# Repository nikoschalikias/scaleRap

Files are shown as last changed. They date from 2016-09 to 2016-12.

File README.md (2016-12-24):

# scaleRap   

A scaleable and robust open-hardware Reprap 3D printer based on aluminium profile 40mm. Designed in Fusion 360 CAD. [project page](https://nikoschalikias.github.io/scaleRap/)  

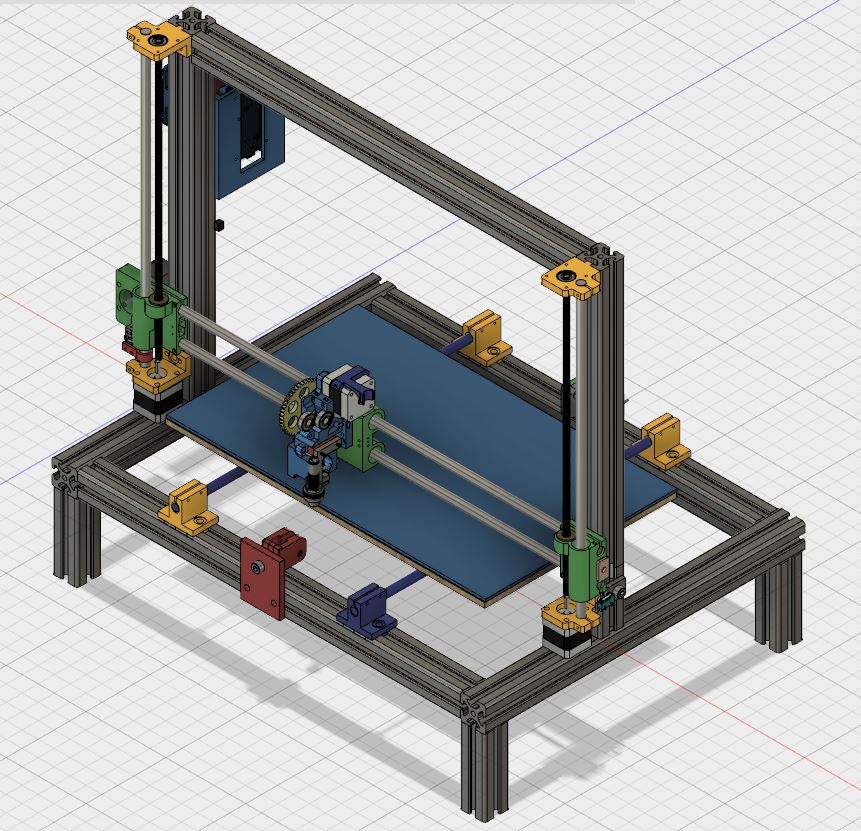
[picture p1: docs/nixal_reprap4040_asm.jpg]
nixal i3 nixal_reprap4040 3D printer
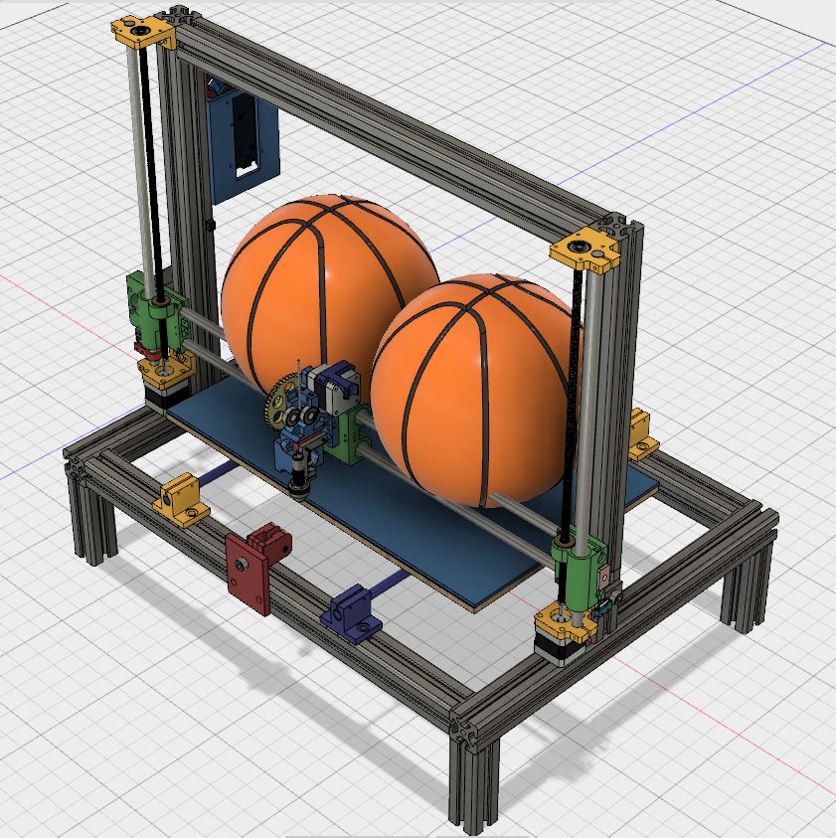
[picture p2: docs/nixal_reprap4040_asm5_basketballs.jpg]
nixal i3 nixal_reprap4040 3D printer
   
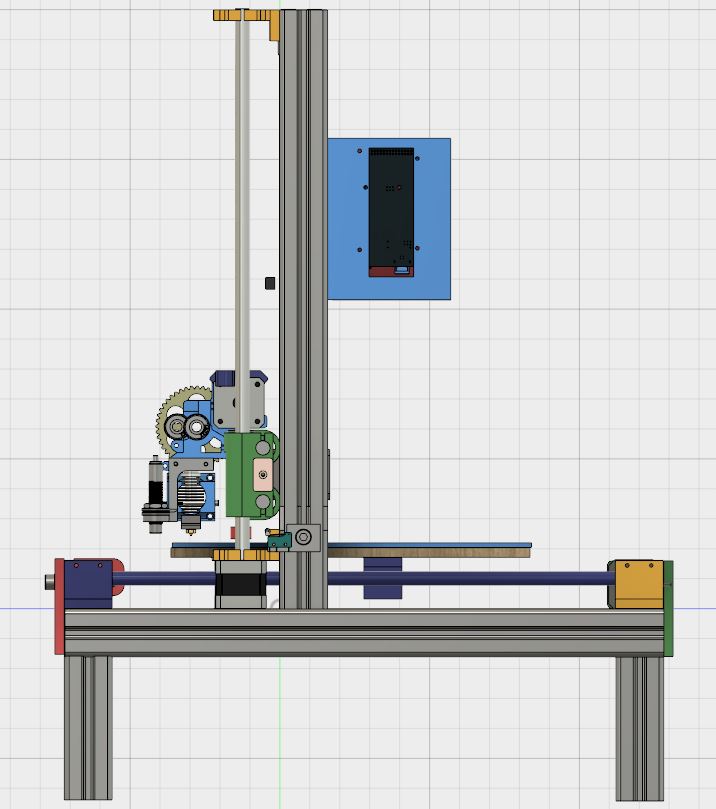
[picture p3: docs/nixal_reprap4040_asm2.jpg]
nixal i3 nixal_reprap4040 3D printer
 
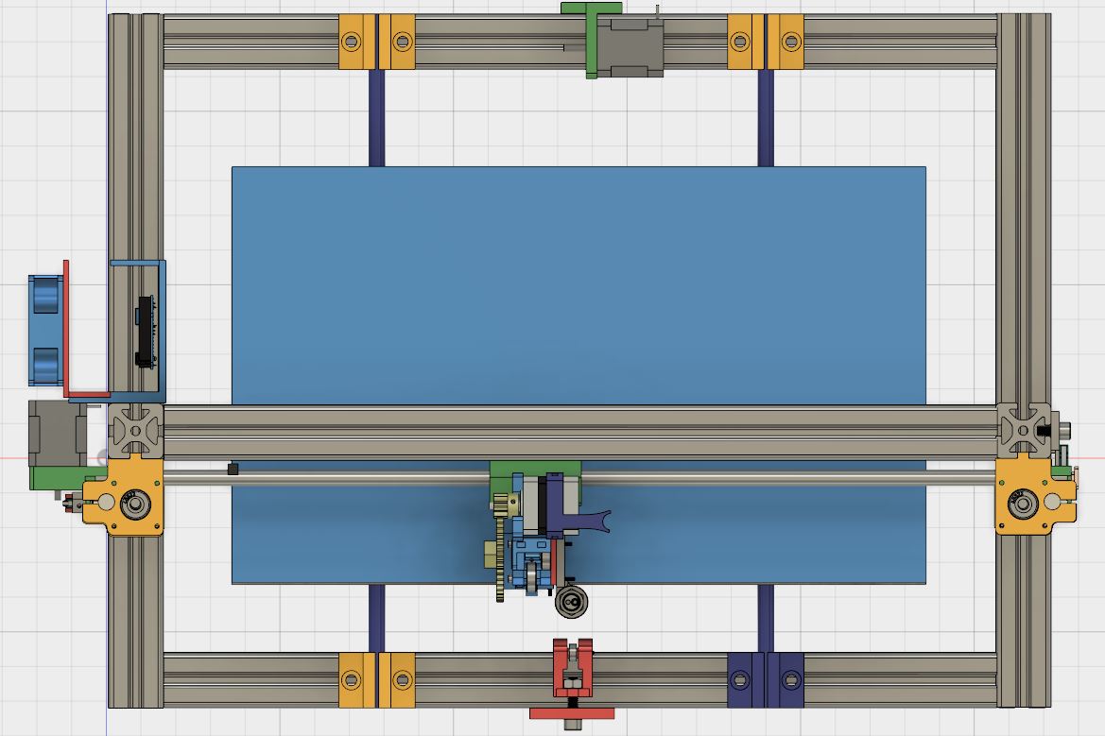
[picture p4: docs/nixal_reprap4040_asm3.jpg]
nixal i3 nixal_reprap4040 3D printer
 
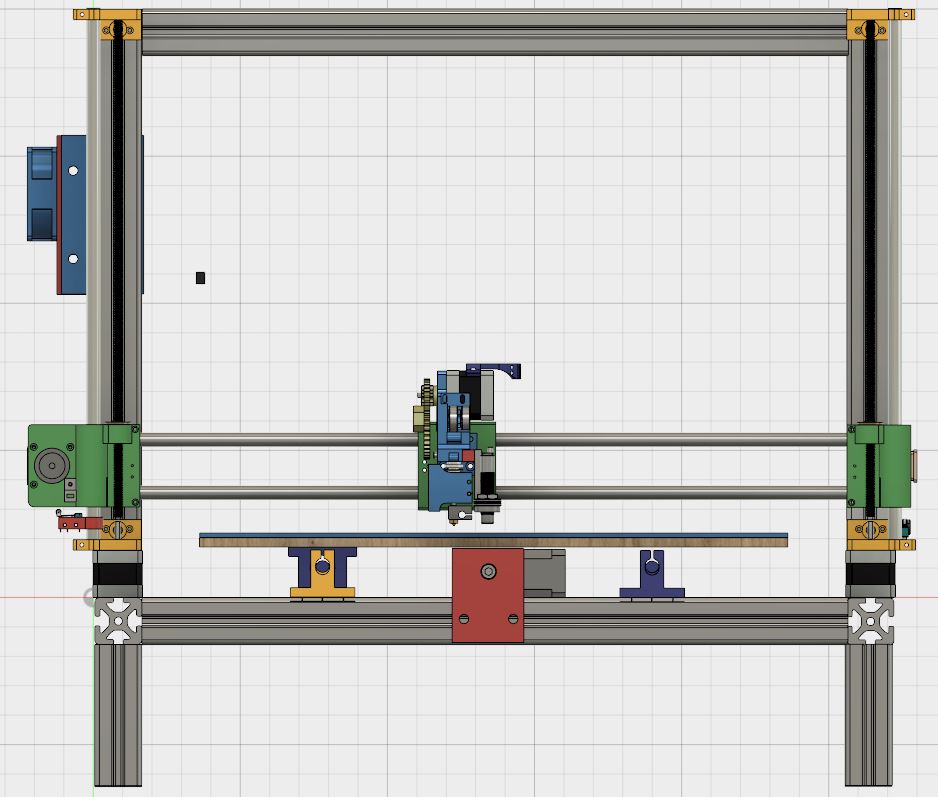
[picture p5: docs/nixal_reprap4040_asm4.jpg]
nixal i3 nixal_reprap4040 3D printer


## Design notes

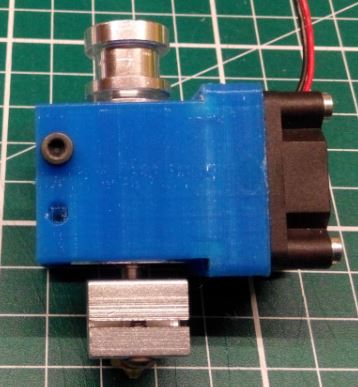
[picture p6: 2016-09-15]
docs/nixal_reprap4040_e3dsecureFan30mm_10.JPG

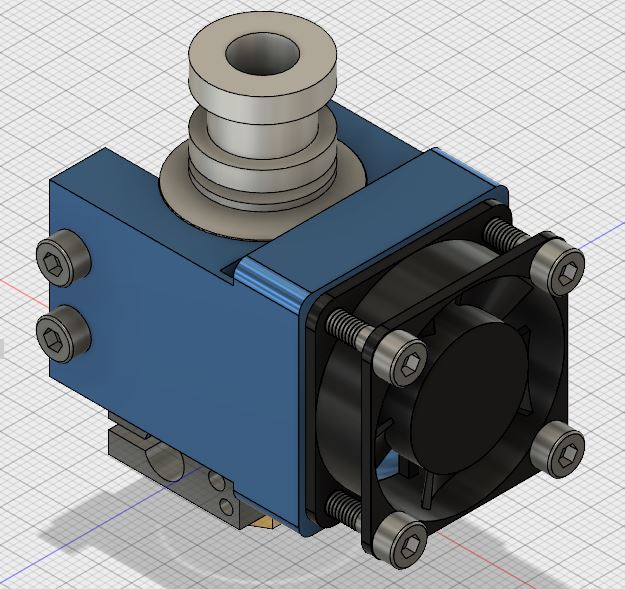
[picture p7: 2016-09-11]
docs/nixal_reprap4040_e3dsecureFan30mm_2.JPG

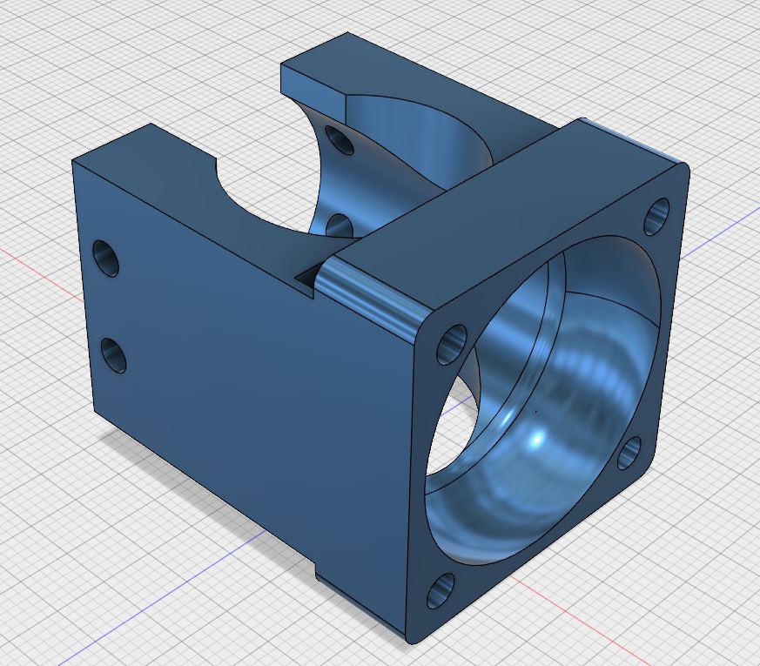
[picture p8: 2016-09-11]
docs/nixal_reprap4040_e3dsecureFan30mm_6.JPG

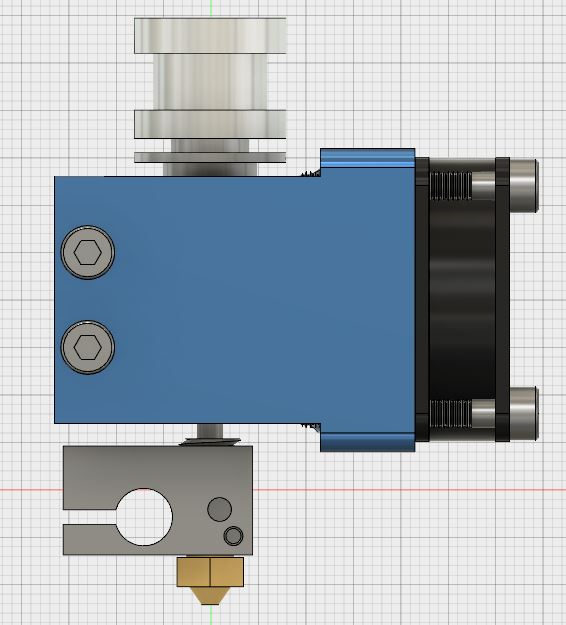
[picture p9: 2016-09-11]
docs/nixal_reprap4040_e3dsecureFan30mm_5.JPG

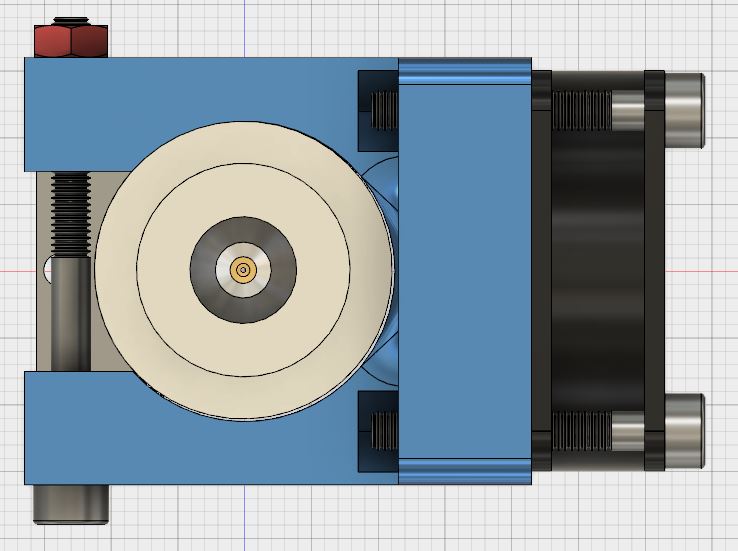
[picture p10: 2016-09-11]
docs/nixal_reprap4040_e3dsecureFan30mm_3.JPG

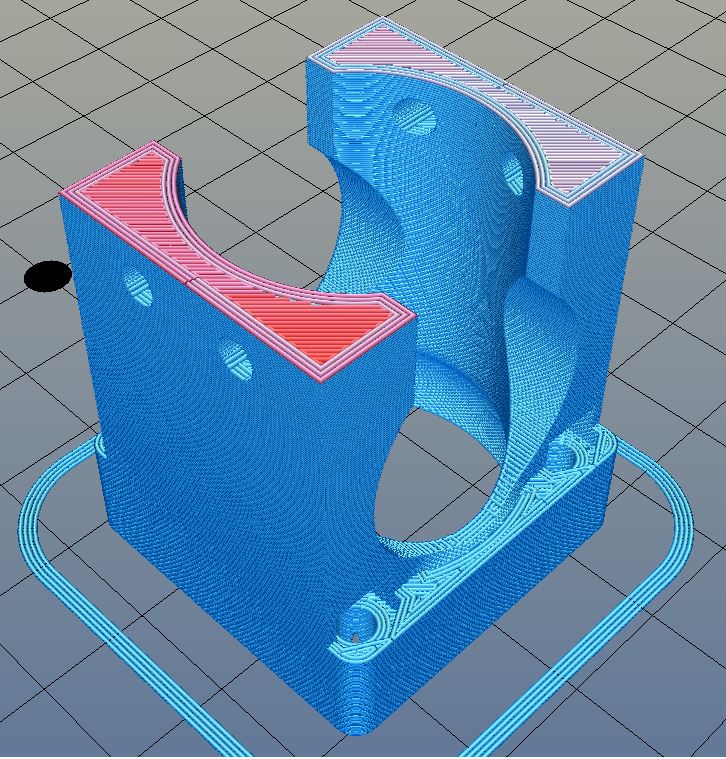
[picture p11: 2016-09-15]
docs/nixal_reprap4040_e3dsecureFan30mm_8.JPG

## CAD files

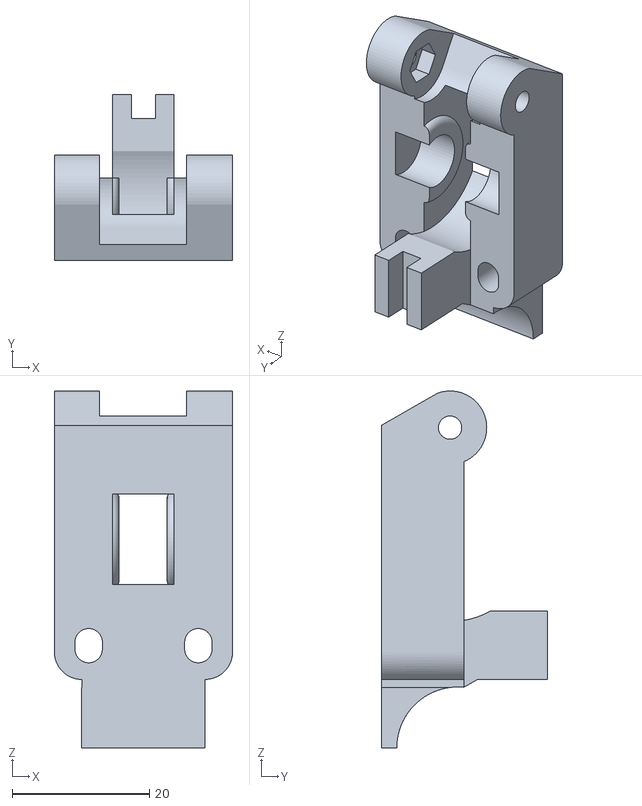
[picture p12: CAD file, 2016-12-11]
stl/nixal_reprap4040_guidler.stl
26.0 x 24.2 x 52.1

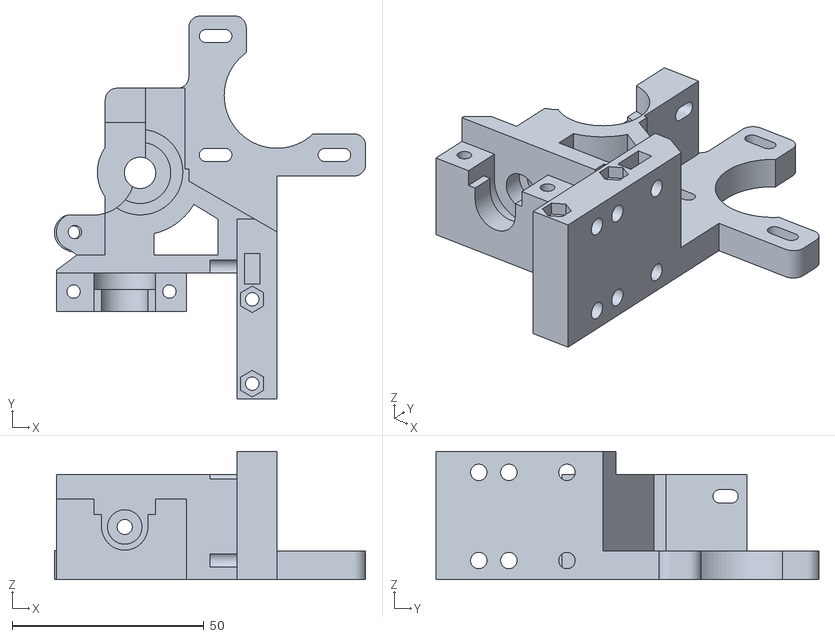
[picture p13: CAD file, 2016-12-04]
stl/nixal_reprap4040_GregsWadesReloadedBody_3mm.stl
81.2 x 99.9 x 33.5

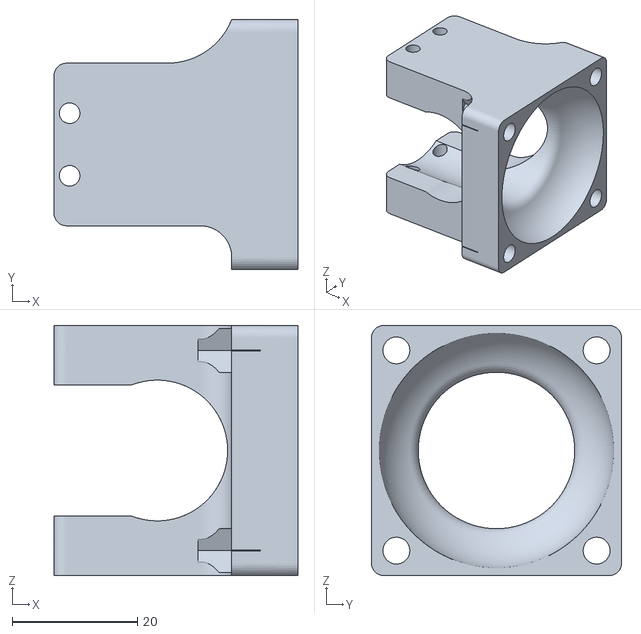
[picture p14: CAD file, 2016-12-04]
stl/nixal_reprap4040_e3dSecureFan40mm.stl
39.0 x 40.0 x 40.0

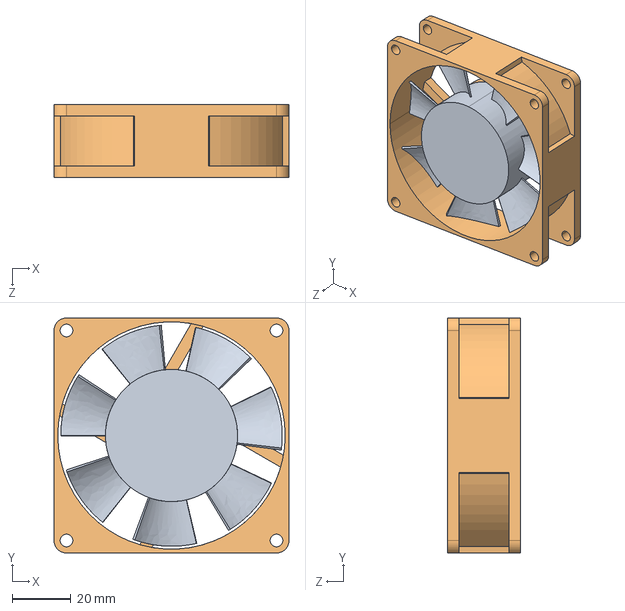
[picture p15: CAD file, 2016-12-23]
step/KD1208PTS3.step
80.0 x 80.0 x 25.0 mm
FanKD1208PTS3_KD1208PTS3
Fan_HouseKD1208PTS3_KD1208PTS3

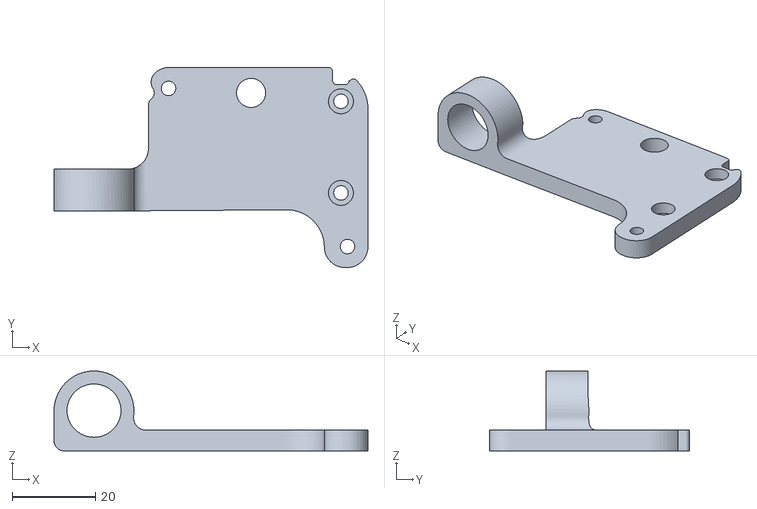
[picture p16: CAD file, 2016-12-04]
stl/nixal_reprap4040_bracketInductiveCentrifugal.stl
75.4 x 48.1 x 19.2

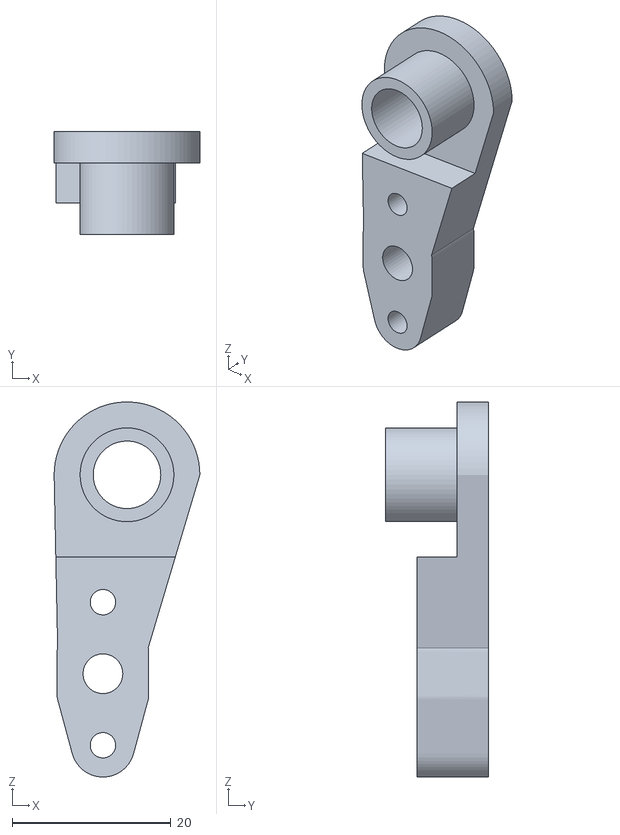
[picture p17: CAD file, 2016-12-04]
stl/BLTOUCH-BRACKET.stl
18.3 x 13.0 x 47.2

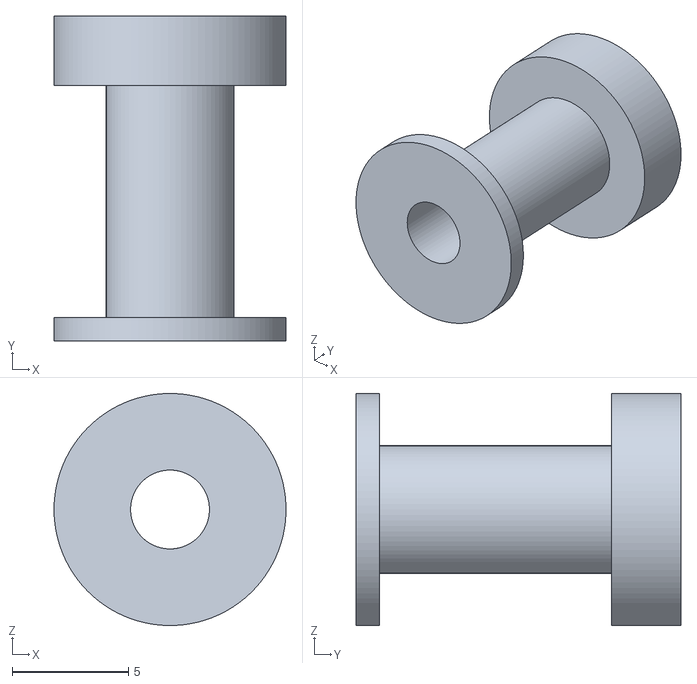
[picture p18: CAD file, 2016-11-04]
stl/nixal_reprap4040_coil.stl
10.00 x 14.0 x 10.00

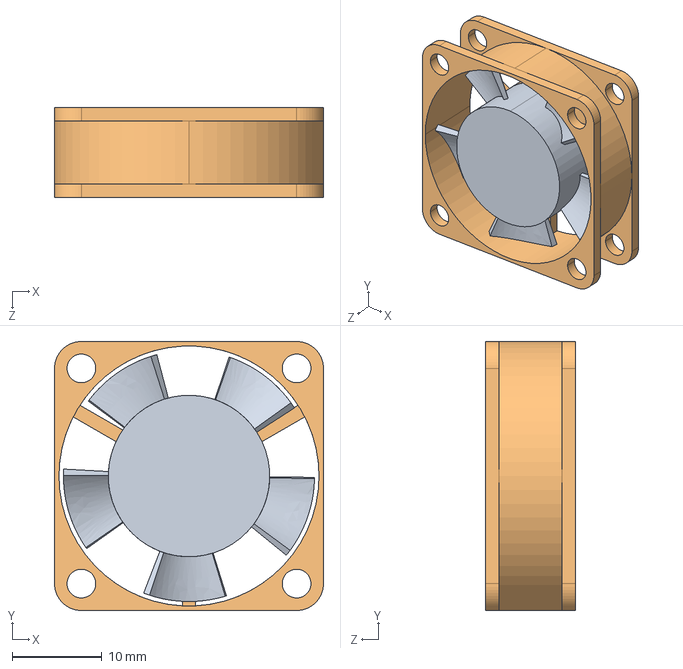
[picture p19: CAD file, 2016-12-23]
step/KDE0503PFB3.step
30.0 x 30.0 x 10.0 mm
FanKDE0503PFB3_KDE0503PFB3
Fan_HouseKDE0503PFB3_KDE0503PFB3

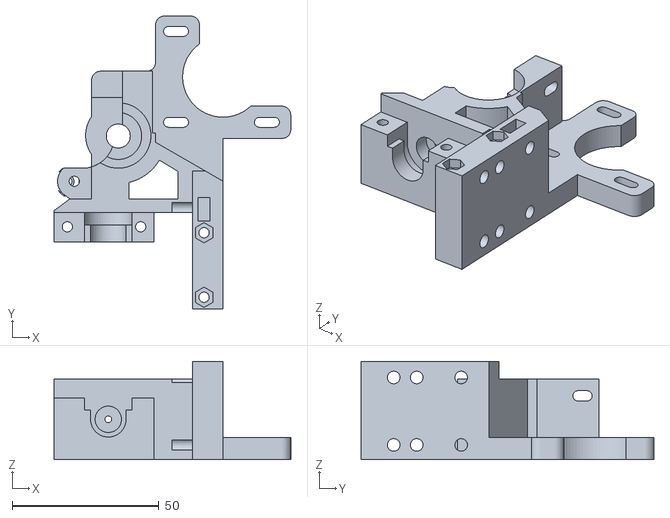
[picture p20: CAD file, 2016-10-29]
stl/nixal_reprap4040_GregsWadesReloadedBody_1.75mm.stl
80.7 x 99.9 x 33.5

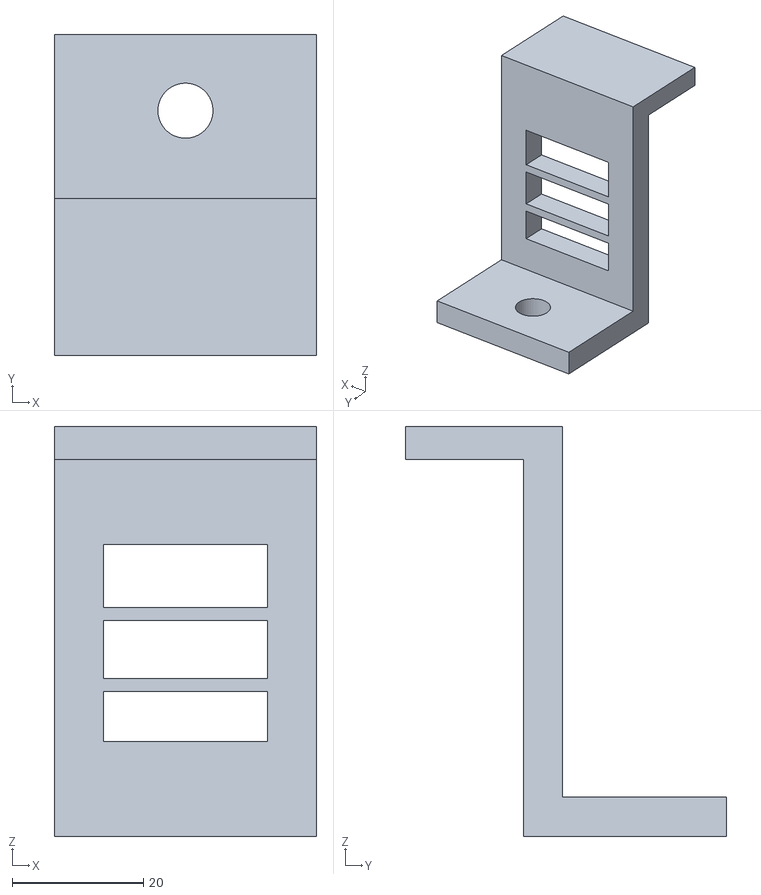
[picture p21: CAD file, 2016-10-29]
stl/nixal_reprap4040_psuHolder1.stl
40.0 x 49.0 x 62.5

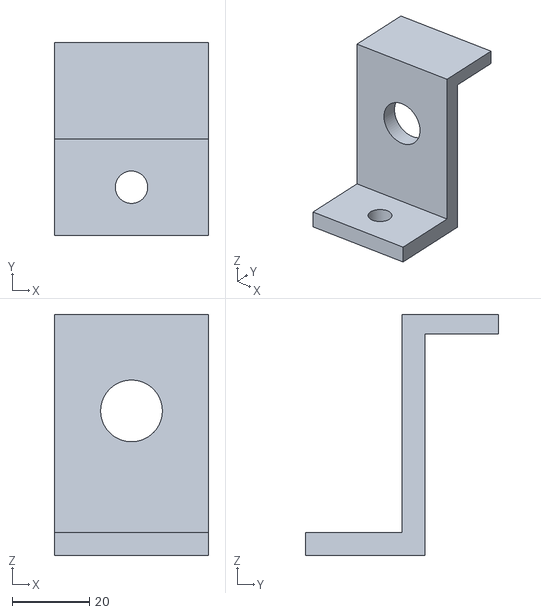
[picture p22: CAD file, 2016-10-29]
stl/nixal_reprap4040_psuHolder2.stl
40.0 x 50.0 x 62.5

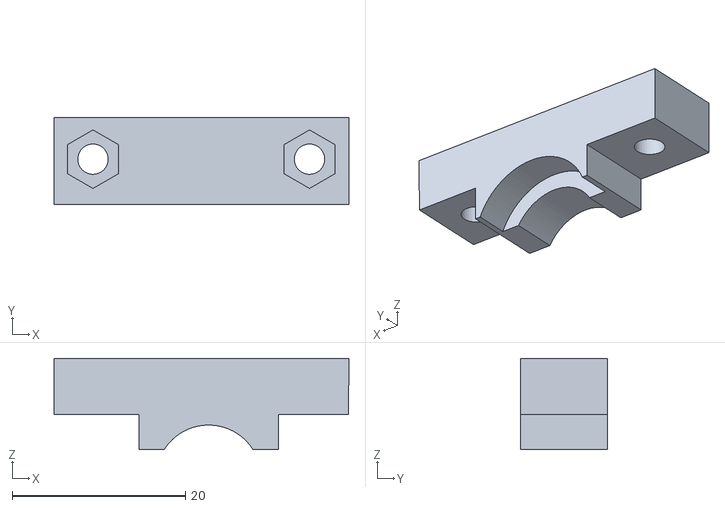
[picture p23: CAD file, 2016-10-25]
stl/nixal_reprap4040_GregsWadesReloadedCap.stl
34.1 x 10.00 x 10.5

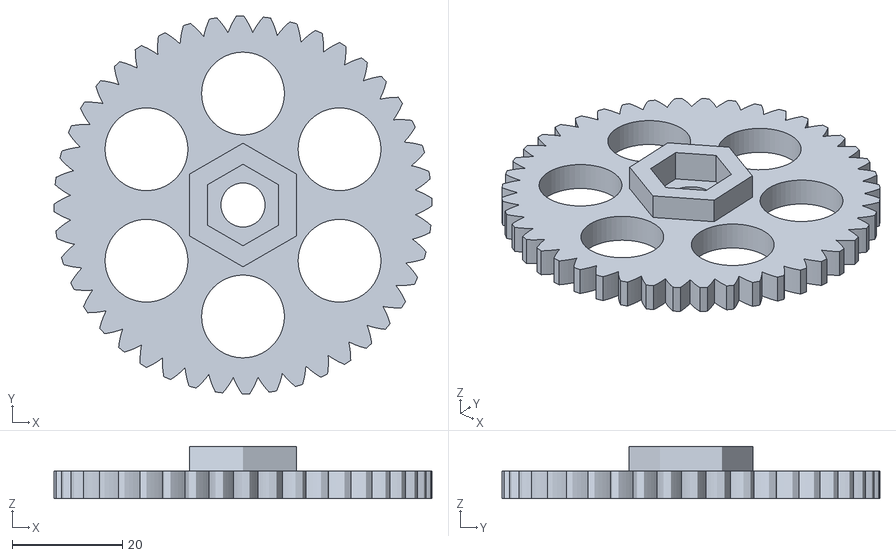
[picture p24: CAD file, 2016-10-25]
stl/nixal_reprap4040_gregWadesLarge44.stl
68.5 x 68.5 x 9.50

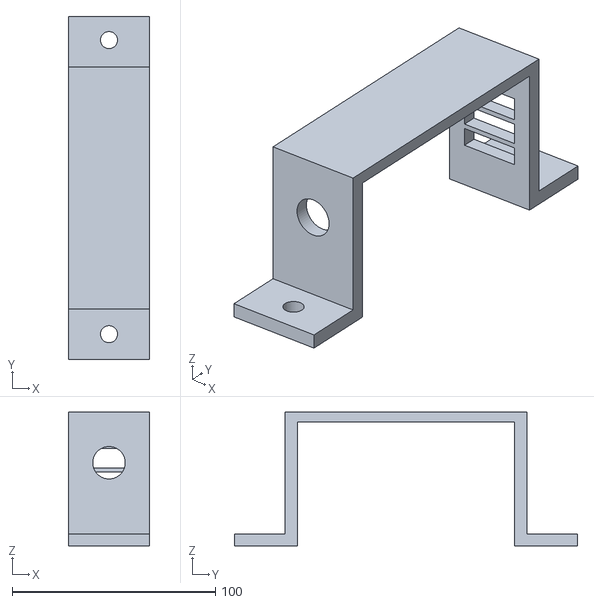
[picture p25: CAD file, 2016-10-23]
stl/nixal_reprap4040_psuHolder.stl
40.0 x 169.0 x 66.0

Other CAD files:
stl/nixal_reprap4040_guidler_1.75mm.stl
stl/nixal_reprap4040_centrifugalFanDuctVolcano.stl
stl/nixal_reprap4040_gregWadesGears_Large44.stl
stl/nixal_reprap4040_centrifugalFanDuct.stl
fusion360/BLTOUCH-BRACKET.f3d
fusion360/M8_NUT.f3d
fusion360/gregWadesGears.f3d
fusion360/item4040_front_back.f3d
fusion360/item4040_leg.f3d
fusion360/item4040_side.f3d
fusion360/item4040_vertical.f3d
fusion360/item_4040.f3d
fusion360/nixal_prusaI3_Ybracket.f3d
fusion360/nixal_prusaI3_spoolHolderClear.f3d
fusion360/nixal_repra[4040_Yidler.f3d
fusion360/nixal_reprap4040_GregWadesReloaded_cap.f3d
fusion360/nixal_reprap4040_GregsWadesReloadedBody.f3d
fusion360/nixal_reprap4040_GregsWadesReloadedCap.f3d
fusion360/nixal_reprap4040_Xtensioner.f3d
fusion360/nixal_reprap4040_XtensionerHolder.f3d
fusion360/nixal_reprap4040_Ybearing.f3d
fusion360/nixal_reprap4040_Yidler.f3d
fusion360/nixal_reprap4040_Ymotor.f3d
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

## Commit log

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2016-07-09 print item profile to test how it feels
    [item_4040.stl]
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2016-07-10 non 4040 Zbracket reduced hole for 8mm screw instead 22 for ball bearing
    [nixal_reprap_ZbracketCompatible_non4040.f3d, nixal_reprap_ZbracketCompatible_non4040.stl]
2016-07-10 yBRACKET for 12.7mm shaft to test an existing shaft from inkjet printer
    [nixal_reprap_Ybracket.f3d, nixal_reprap_Ybracket.stl]
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2016-07-13 zbrackets updates for acrylic prusa, new Xcariage for acrylic & 4040
    [nixal_reprap_Xcariage.f3d, nixal_reprap_Xcariage.stl, nixal_reprap_ZbracketCompatible.f3d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]
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2016-07-15 Xcariage redesign
    [nixal_reprap_Xcariage.f3d, nixal_reprap_Xcariage.stl]
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2016-08-16 Ybearing updated, compatible with of the shelf Aluminium
    [nixal_reprap4040_Ybearing.f3d, nixal_reprap4040_Ybearing.stl]
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2016-08-21 updated XZ doesn't need support.Replaces Xidler Xmotor who removed
    [nixal_reprap_XZ_Comparible_robust.f3d, nixal_reprap_XZ_Comparible_robust.stl, nixal_reprap_XidlerComparible_robust.f3d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]
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2016-08-21 nixal_XZ with suppressed cut extrude, works for both motor and idle
    [nixal_reprap_XZ_Comparible_robust.f3d, nixal_reprap_XZ_Comparible_robust.stl, nixal_reprap_XZ_Compatible_robust.f3d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]
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2016-08-21 XZ shaft tightening slot length adjusted to end of shafts
    [nixal_reprap_XZ_Compatible_robust.f3d, nixal_reprap_XZ_Compatible_robust.stl, nixal_reprap_XZ_Compatible_robust_idler.stl]
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2016-08-26 move 8mm screw 20mm from edge instead 16mm
    [nixal_prusaI3_spoolHolderClear.f3d, nixal_prusaI3_spoolHolderClear.stl]
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2016-08-26 XZ with 10.5x10.5mm tunel for belt tightener
    [nixal_reprap_XZ_Compatible_robust.f3d, nixal_reprap_XZ_Compatible_robust.stl, nixal_reprap_XZ_Compatible_robust_idler_PRINT_MIRRORED.stl]
2016-08-26 Xtensioner bumps adjasted so ball bearing 3x5x13 fits
    [nixal_reprap4040_Xtensioner.f3d, nixal_reprap4040_Xtensioner.stl]
2016-08-27 SpoolHolderClear 8mm hole moved 2mm to the bottom
    [nixal_prusaI3_spoolHolderClear.f3d, nixal_prusaI3_spoolHolderClear.stl]
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2016-08-27 ramps connector windows larger can take 4x4pin connectors (pitch 5mm)each window
    [nixal_reprap_4040_Ramps.stl]
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2016-08-28 new GregWadesReloaded Cap and body update for cap
    [nixal_reprap4040_GregWadesReloaded.f3d, nixal_reprap4040_GregWadesReloaded.stl, nixal_reprap4040_GregWadesReloaded_cap.f3d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]
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2016-08-29 GregWadesReloaded increased back depth to avoid big gear touch the Xcarriage, motor closer to big gear, improved print suppports for the 2 hinges
    [nixal_reprap4040_GregWadesReloaded.f3d, nixal_reprap4040_GregWadesReloaded.stl]
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2016-08-30 Xcariage more deep and robust, XZ with holes for endSwitch
    [nixal_reprap_XZ_Compatible_robust.f3d, nixal_reprap_XZ_Compatible_robust.stl, nixal_reprap_Xcariage.f3d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]
2016-08-31 XZ cut-extrude so TR8 coupler does not touch
    [nixal_reprap_XZ_Compatible_robust.f3d, nixal_reprap_XZ_Compatible_robust.stl]
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2016-09-03 endStop offset from 20 to 10mm, XZ fillets and M3 nut for shaft tightening update
    [nixal_reprap_4040_endStop.f3d, nixal_reprap_4040_endStop.stl, nixal_reprap_XZ_Compatible_robust.f3d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]
2016-09-03 mirrored XZ, thing1091522 fun duct Solidworks file imported to FUSION360, start sketch
    [nixal_reprap_XZ_Compatible_robust_idler_PRINT_MIRRORED.stl]
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2016-09-04 Induction sensor lower, hole to avoid air flow blocking
    [nixal_reprap4040_inductiveMount.f3d, nixal_reprap4040_inductiveMount.stl]
2016-09-04 GregWadesReloaded_cap updated->thicker more robust avoid bending,works as spacer for inductive
    [nixal_reprap4040_GregWadesReloaded.f3d, nixal_reprap4040_GregWadesReloaded_cap.f3d]
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2016-09-04 inductiveMount large fillet to avoid interference with the heater/thermistor cables
    [nixal_reprap4040_inductiveMount.f3d, nixal_reprap4040_inductiveMount.stl]
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2016-09-04 e3dSecureFan30mm fan holes at 24mm dist instead 25
    [nixal_reprap4040_e3dSecureFan30mm.f3d, nixal_reprap4040_e3dSecureFan30mm.stl]
2016-09-04 e3dSecureFan30mm reduced to same fan dist from hotend axis, for compatibility with thing 1519723 and 1344418
    [nixal_reprap4040_e3dSecureFan30mm.f3d, nixal_reprap4040_e3dSecureFan30mm.stl]
2016-09-04 e3dSecureFan30mm screw holes changed to 2.8mm to self-tap M3 machine screws
    [nixal_reprap4040_e3dSecureFan30mm.f3d, nixal_reprap4040_e3dSecureFan30mm.stl]
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2016-09-05 e3dSecureFan30mm: thicker again, was too fragile, jpg added
    [nixal_reprap4040_e3dSecureFan30mm.f3d, nixal_reprap4040_e3dSecureFan30mm.stl]
2016-09-11 e3dSecureFan30mm M3x22 and nuts, fan, extruder, screws, nuts all in design
    [091202__3_16-mattssons.step, 091202__3_22-mattssons.step, 091202__3_25-mattssons.step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]
2016-09-15 Ymotor and idler above profile (now 5mm higher) gain Y size 80mm if both mounted externally
    [nixal_prusaI3_Ybracket.f3d, nixal_prusaI3_Ybracket.stl, nixal_repra[4040_Yidler.f3d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]
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2016-10-09 GregWadesReloaded back compatible with i3 Flilament hole for 1.75 and parametric distance from hobed bolt Supports separated, to test printout on kossel
    [nixal_reprap4040_GregsWadesReloadedBody.f3d, nixal_reprap4040_GregsWadesReloadedBody.stl, nixal_reprap4040_GregsWadesReloadedCap.f3d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]
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2016-10-15 bracketInductiveCentrifugal clearances for E3D cap screws
    [nixal_reprap4040_bracketInductiveCentrifugal.f3d, nixal_reprap4040_bracketInductiveCentrifugal.stl]
2016-10-15 fixed bracket extrude that was extruding the body and cap
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2016-10-16 bracketInductiveCentrifugal updates after printout, GregWades hexagon nuts pockets and 3mm version STL large gear tigheter hexagon nut e3dSecureFan30mm hexaon nut pockets
    [gregWadesGears_Large.stl, nixal_reprap4040_GregsWadesReloadedBody_3mm.stl, nixal_reprap4040_GregsWadesReloadedCap.stl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]
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2016-10-17 gregWadesGears large gear hexagon pocket for screw --> 10mm offset gear 7mm thick from 5mm before gregWadesGears_Large44 new stl
    [gregWadesGears.f3d, nixal_reprap4040_centrifugalFanDuct.stl, nixal_reprap4040_gregWadesGears_Large44.stl]
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2016-10-17 gregWadesGears, tight hexagon for boltM8
    [gregWadesGears.f3d]
2016-10-19 centrifugalFanDuct parametric for normal and volcano gregWadws tidy-up, third party volcano included,
    [nixal_reprap4040_centrifugalFanDuctVolcano.stl, nixal_reprap4040_gregWadesLarge44.stl]
2016-10-23 new Fusion360 Guidler based on fixers_Extruder_guidler_with_lever_RICHRAP.stl
    [nixal_reprap4040_guidler.f3d, nixal_reprap4040_guidler.stl]
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2016-10-23 GregWadesReloaded enhancements for post printing text in front for 1.75 or 3mm filament updated support for bearing hole and guidler hindge bearing hole 22.3mm from 22mm, was too tight
    [nixal_reprap4040_GregsWadesReloadedBody.stl, nixal_reprap4040_GregsWadesReloadedBody_1.75.stl]
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2016-10-25 GregWadesReloaded: Cap 4mm thiner avoiding screws conflict Body holes 3.5 from 3.2mm for bracketInductiveCentrifugal Text 1.75 Arial Black Bold from just Arial, repositioned
    [nixal_reprap4040_GregsWadesReloadedBody_1.75mm.stl, nixal_reprap4040_GregsWadesReloadedCap.stl]
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2016-10-27 GregWadesReloaded and guidler body nut pockets for guidler screws aligned and reduced size top 2 holes M4 at the back removed, not used Guidler updated inside GregWadesReloaded assembly for nut pocke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
    [nixal_reprap4040_GregsWadesReloadedBody_1.75mm.stl, nixal_reprap4040_guidler_1.75mm.stl]
2016-10-29 GregWadesReloaded: supressed small hindge from body face psuHolder:split in 2 pieces, depth reduced by 3.5mm
    [nixal_reprap4040_GregsWadesReloadedBody_1.75mm.stl, nixal_reprap4040_psuHolder.f3d, nixal_reprap4040_psuHolder1.stl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]
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2016-11-30 BLTOUCH-BRACKET REDESIGNED FOR 8mm SCREW
    [BLTOUCH-BRACKET.f3d, BLTOUCH-BRACKET.stl]
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
